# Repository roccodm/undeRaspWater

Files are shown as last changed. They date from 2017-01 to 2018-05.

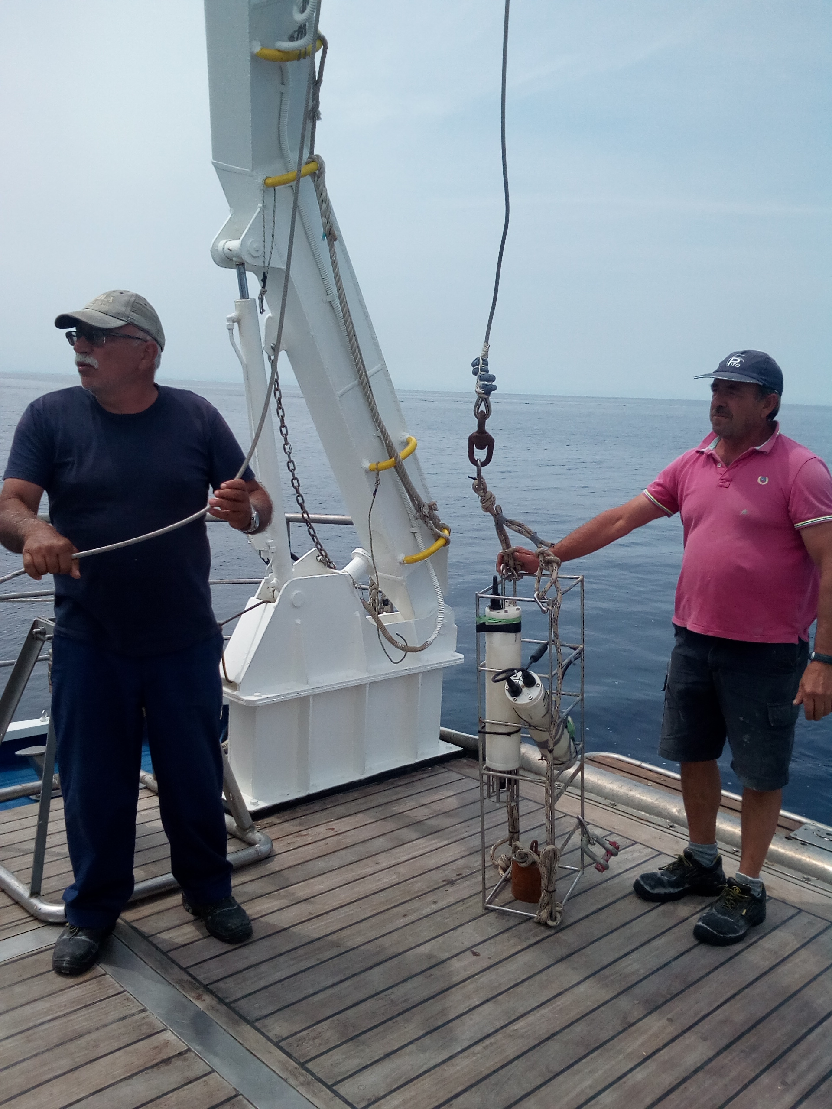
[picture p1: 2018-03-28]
Images/test/IMG_20170610_120925.jpg

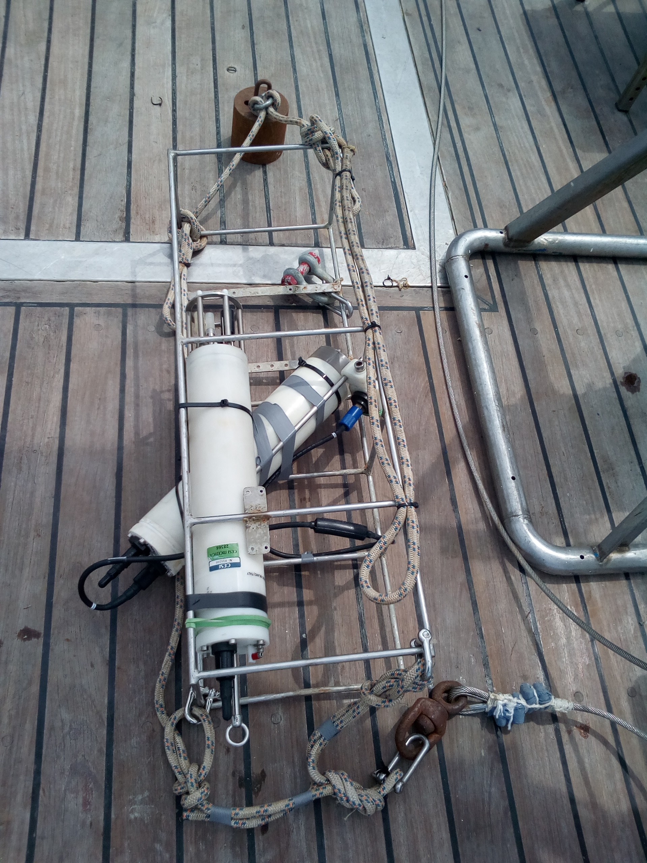
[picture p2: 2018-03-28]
Images/test/IMG_20170610_120815.jpg

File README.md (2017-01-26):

# undeRaspWater

Some useful links:
https://blog.retep.org/2014/02/15/connecting-an-arduino-to-a-raspberry-pi-using-i2c/

https://www.futurashop.it/Allegato_PDF_IT/7100-FT1073K.pdf

https://oscarliang.com/raspberry-pi-arduino-connected-i2c/

http://int03.co.uk/blog/2015/01/11/raspberry-pi-gpio-states-at-boot-time/
https://www.raspberrypi.org/documentation/configuration/pin-configuration.md

Per il voltmetro/amperometro:
http://www.adrirobot.it/arduino/voltmetro_amperometro/Arduino_voltmetro-amperometro.htm

Sulla raspberry vanno dissaldate le resistenza R1 e R2 per garantire il funzionamento del bus I2C quando è spenta. Il pullup è sulla scheda RTC, magari prevedere un pullup da 10K di backup

Per il driver dei led: http://electronics-diy.com/electronic_schematic.php?id=1012

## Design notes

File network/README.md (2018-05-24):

= Networking scripts =

A small script to provied information on networking performance

== Usage ==

You need `iperf3`, `ping`, `sed`, `tr` installed on your machine and the raspberry PI.

- On the RPI, run: `iperf3 -s -J` (`-J` ensures json output)
- On your computer, run: `sh network_test.sh RPI_IP` (where `RPI_IP` is the network address of the raspberry PI)
- Wait for script completion, you will get an output like: `Written log file to: network_test-TIMESTAMP.log`.
  That file will contians JSON data on the network tests.

You can invert the commands between the RPI and your computer if you feel the RPI might suffer when running as server.
It would be, in any case, good to make a comparison between the two logs.

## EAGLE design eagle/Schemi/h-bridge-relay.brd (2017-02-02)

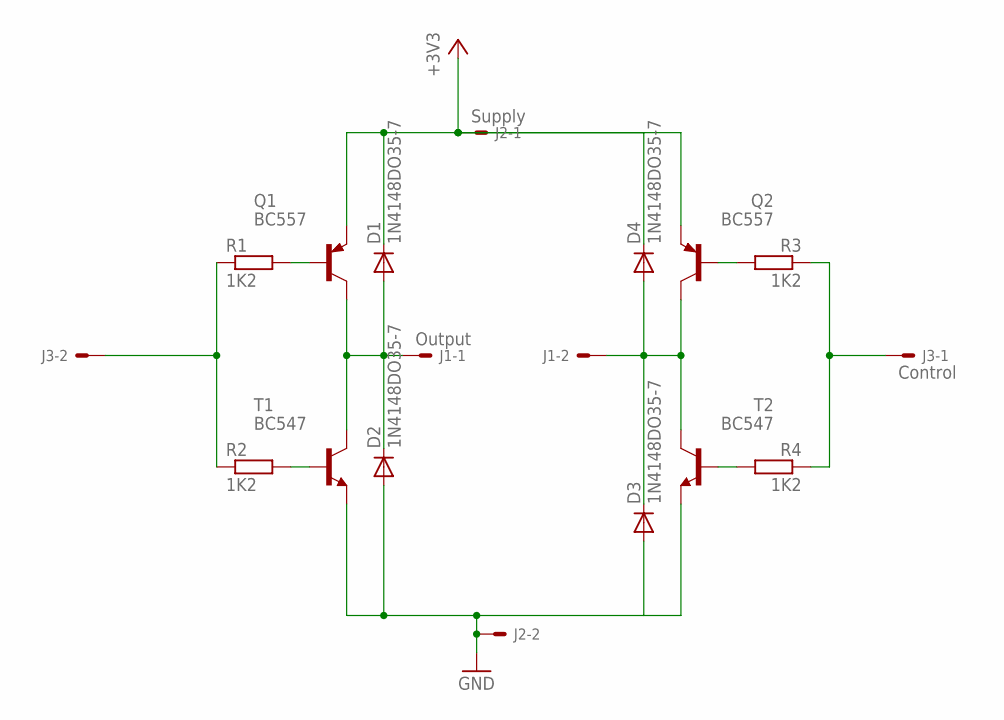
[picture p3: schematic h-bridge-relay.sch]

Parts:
D1, D2, D3, D4: 1N4148DO35-7; DO35-7
J1: Output; 6410-02
J2: Supply; 6410-02
J3: Control; 6410-02
Q1, Q2: BC557; TO92
R1, R4: 1K2; 0207/7
R2: 1K2; 0207/12
R3: 1K2; 0207/2V
T1, T2: BC547; TO92

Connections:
+3V3: D1.C, D4.C, J2.1, Q1.1 (E), Q2.1 (E)
GND: D2.A, D3.A, J2.2, T1.1 (E), T2.1 (E)
unnamed: R2.2, T1.2 (B)
unnamed: Q1.2 (B), R1.2
unnamed: Q2.2 (B), R3.2
unnamed: R4.2, T2.2 (B)
unnamed: D1.A, D2.C, J1.1, Q1.3 (C), T1.3 (C)
unnamed: D3.C, D4.A, J1.2, Q2.3 (C), T2.3 (C)
unnamed: J3.1, R3.1, R4.1
unnamed: J3.2, R1.1, R2.1

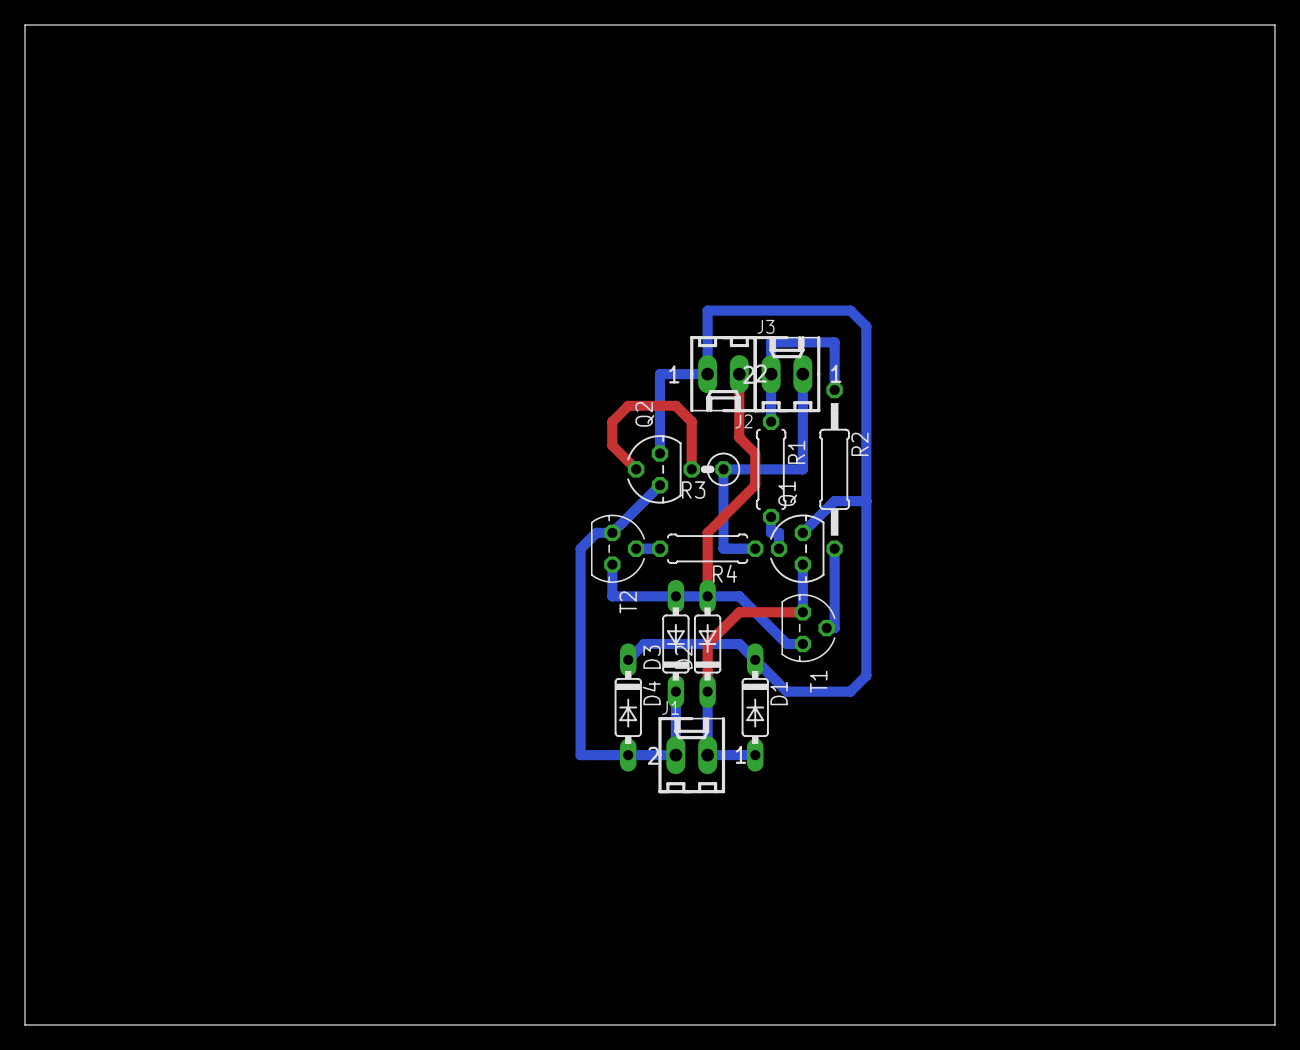
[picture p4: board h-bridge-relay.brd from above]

Board: 2 copper layers, 100.0 x 80.0 mm, 15 parts (0 on the bottom side), 10 nets.

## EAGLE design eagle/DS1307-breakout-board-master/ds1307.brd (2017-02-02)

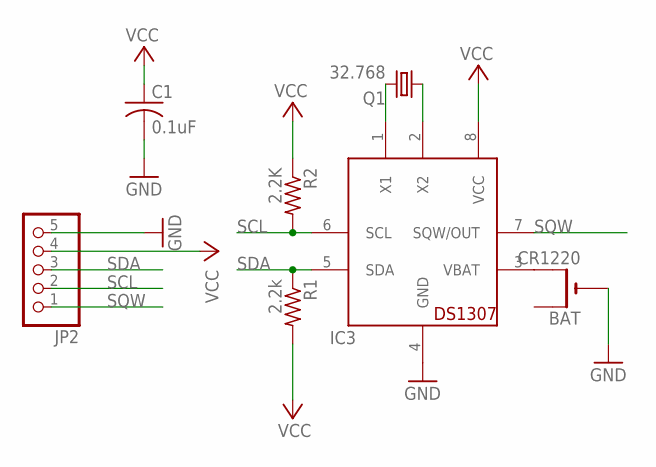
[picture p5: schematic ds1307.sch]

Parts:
BAT: CR1220; CR1220-THM
C1: 0.1uF; C025-025X050
IC3: DS1307; DIL08
JP2: PINHD-1X5; 1X05
Q1: 32.768; TC38H
R1: 2.2k; 0207/10
R2: 2.2K; 0207/10

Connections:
GND: BAT.-, C1.2, IC3.4 (GND), JP2.5
unnamed: IC3.1 (X1), Q1.2
unnamed: IC3.2 (X2), Q1.1
unnamed: BAT.+2 (+1), IC3.3 (VBAT)
SCL: IC3.6 (SCL), JP2.2, R2.2
SDA: IC3.5 (SDA), JP2.3, R1.1
SQW: IC3.7 (SQW/OUT), JP2.1
VCC: C1.1, IC3.8 (VCC), JP2.4, R1.2, R2.1

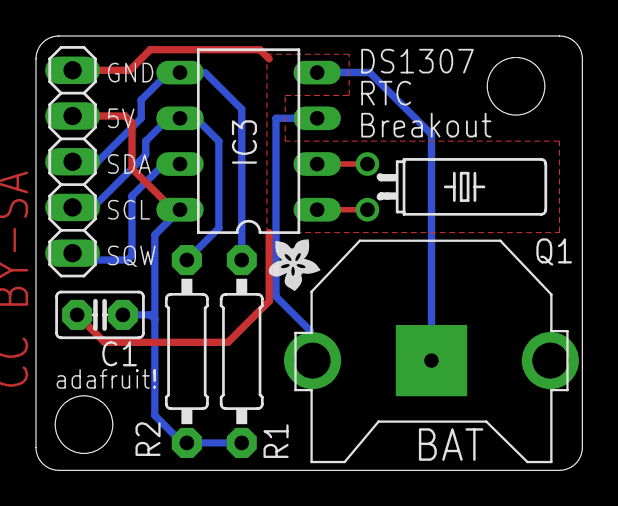
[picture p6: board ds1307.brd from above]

Board: 2 copper layers, 30.4 x 24.1 mm, 8 parts (0 on the bottom side), 8 nets.

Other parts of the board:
U$1: ADAFRUIT200MIL

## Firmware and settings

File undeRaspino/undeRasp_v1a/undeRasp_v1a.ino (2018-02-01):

/*************************************************************************************** 
 *  UnderRaspino
 ***************************************************************************************
 *  v. 1.0a
 *  by Rocco De Marco - rocco.demarco@an.ismar.cnr.it
 ***************************************************************************************/

// MESSAGES
#define START_MSG "\n\nUnderRaspino Ready."
#define I2C_INIT_FAIL "FATAL: i2c bus error"
#define RTC_INIT_FAIL "FATAL: RTC error"
#define LOWBAT "Low battery to start RB"
#define RASP_FAIL "Unable to powerup RB"
#define RASP_NO_HB "Unable to receive Heartbeat from RB"
#define RASP_STARTING "Starting RB"
#define RASP_STOP "RB stopped"
#define MENU1 "\nA\tpower used(A)\nC\tARD temperature\nd/D\tread/write EEPROM datestam (YYMMDDHHMMXXX)\nE/e\tclear/read last error in eprom"
#define MENU2 "\nH/h\tset/read heartbeat\nK/k\tenable/disable RB serial out\nL/l\tTurn on/off mosfet\nM\tSecs left to start RB\nO/o\tset/read keep on RB (use q to quit)\nP/p\tenable/disable ARD serial out\nQ\tQuit RB"
#define MENU3 "\nR\tRB running status\nS/s\tstart/stop RB relay\nT/t\tSet/read RTC (YYMMDDHHMMSS)\nV\tread voltage\nW\tread watt\n?\tPrint this menu"

// ERR CODES
#define I2C_ERRCODE 81
#define RTC_ERRCODE 82
#define LOWBAT_ERRCODE 83
#define RASP_FAIL_ERRCODE 84
#define RASP_NO_HB_ERRCODE 85

// CONFIG
#define VCC 3.3
#define SERIAL_RASPBERRY_PIN 13
#define SERIAL_ARDUINO_PIN 12
#define RELAY_SET_PIN 9
#define RELAY_RESET_PIN 8
#define OK_LED_PIN 7
#define FAIL_LED_PIN 6
#define RASPBERRY_STATUS_PIN 5
#define MOSFET_PIN 4
#define BAUD_RATE 9600
#define VOLTAGE_PIN A0
#define AMPERE_PIN A1
#define I2C_ADDRESS 0x04
#define I2C_SDA A4
#define I2C_SCL A5
#define RTC_MIN_DATE 1483228800   //1/1/2017 0:0:0
#define BUFFSIZE 21
#define R_ALPHA 0.152             // for V read purpose, R partitor coeff.
#define RASP_SHUTDOWN_TIME 30     // delay for shutdown in seconds
#define MAX_TRY 5                 // max raspberry starting tentatives
#define TRY_DELAY 30              // delay (between tests) in seconds
#define MIN_BATTERY_VOLTAGE 9     // minimum voltage to start raspberry in safe
#define MIN_RASPBERRY_DELAY 10    // in minutes
#define ALT_SAMPLING_TIME 120     // alternative sampling time in case of heartbeat fail. In seconds

// INCLUDES
#include <Wire.h>
#include "RTClib.h"
#include <EEPROM.h>
//#include <avr/wdt.h>      // Watchdog actually not working on arduino pro mini :( Stuks in a reset loop 

// GLOBAL VARS
RTC_DS1307 RTC;
DateTime now;
char buffer[BUFFSIZE];    // general purpose global buffer
bool error_status=false;  // flag setted up in case of fatal errors
bool rasp_running=false;  // raspberry running status flag
bool halt_request=false;  // raspberry asks for halt
bool keep_on=false;
bool heartbeat=false;     // Setted from raspberry via i2c
double i2c_val;           // return value for i2c operations
uint32_t wt=0;            // waketime unix stamp
int unresponsive_count=0; // time incremental counter used in failure cases

/*
 * Function error_handler(errcode, msg)
 * 1) prints an error message on serial connection
 * 2) sets a errcode in eeprom 
 * 3) sets to true global variable error_status
 * 4) turns on a red led
 */
void error_handler(char errcode, const char * msg){
   Serial.println(msg);
   error_status=true; 
   EEPROM.write(7,errcode);
   digitalWrite(OK_LED_PIN,0);
   digitalWrite(FAIL_LED_PIN,1);  // Turn on red led
}

/*
 * Function get_pin_median(pinNumber, readDelay)
 * 
 * Sometimes the adc could read dirty values. To avoid wrong values in critical operations
 * more values are read and stored in an ordered array of odd number of elements. 
 * Sorting the array, the bad value will go in a boundary and, returning the median value
 * (the central element in the array), it's highly probable to get a good value.
 * 
 * The InsertionSort algorithm has been used to sort the values, that is pretty fast (such 
 * as the quicksort algorithm!!!) for small array (under 10 element, optimus is 7).
 * 
 * Input:
 *   PinNumber: analog pin to be read
 *   Delay: optional delay between read
 * Output:
 *   The median value of the array of seven reads (integer)
 */

int get_pin_median (int pinNumber, int readDelay=0){
   int value,v[7];         
   for(int n=0;n<7;n++){                            
      int i=0;
      value=analogRead(pinNumber);
      while (i<n and value<=v[i]) i++;
      for (int j=n-1;j>=i;j--) v[j+1]=v[j];
      v[i]=value;
      delay(readDelay);
  }
  return v[3];
}


/*
 * function rasp_relay (set)
 * turn on/off raspberry
 * sets the global var "rasp_running"
 */

double rasp_relay(bool set){
   if (set) {
       digitalWrite(RELAY_SET_PIN,1);
       delay(100);
       digitalWrite(RELAY_SET_PIN,0);
       rasp_running=true;
       return 1;
   } else {
       digitalWrite(RELAY_RESET_PIN,1);
       delay(100);
       digitalWrite(RELAY_RESET_PIN,0);       
       rasp_running=false;
       return 0;
   }
   
}
/*
 * EPROM data structure
 * ----------------------------------------
 * byte | value
 * ----------------------------------------
 *   1  | Year, last two digits  
 *   2  | Month
 *   3  | Day
 *   4  | Hour
 *   5  | Minute
 *   6  | Timestep for delay (minutes)
 *   7  | Last error code
 * ----------------------------------------
 */

/*
 * Function read_eprom_date()
 * read the eeprom date,time and timestem and returns it in global var buffer
 */
double read_eprom_datetime(){ 
   sprintf(buffer,"%02d%02d%02d%02d%02d%03d",EEPROM.read(1),EEPROM.read(2),EEPROM.read(3),
           EEPROM.read(4),EEPROM.read(5),EEPROM.read(6));  
   // returns -2 that means the the return values are stored on global buffer[]
   return -2;
}


/*
 * Function set_eprom_datetime(string)
 * sets the startup datetime  to given value
 * string format: YYMMDDHHMMXXX where XXX is timestep (max 250)
 */


double set_eprom_datetime(char *data){
   int year=*data * 10 + *(data+1);
   int month=*(data+2) * 10 + *(data+3);
   int day=*(data+4) * 10 + *(data+5);
   int hour=*(data+6) * 10 + *(data+7);
   int minute=*(data+8) * 10 + *(data+9);
   int timestep=*(data+10) * 100 + *(data+11) * 10 + *(data+12);
   if (year<17 || month<=0 || month>12 || day<=0 || day >31 || hour>=24 || minute>=60 || 
       timestep <=0 || timestep >250) return -1.4;  // Problem in conversion
   EEPROM.write(1,year);
   EEPROM.write(2,month);
   EEPROM.write(3,day);   
   EEPROM.write(4,hour);
   EEPROM.write(5,minute);
   EEPROM.write(6,timestep);  
   update_waketime(); 
   sprintf(buffer,"ok");
   return -2;
}

/*
 * Function set_rct_datetime(string)
 * sets the rtc datetime to given value
 * string format: YYMMDDHHMMSS
 */

double set_rtc_datetime(char *data){
   int year=*data * 10 + *(data+1);
   int month=*(data+2) * 10 + *(data+3);
   int day=*(data+4) * 10 + *(data+5);
   int hour=*(data+6) * 10 + *(data+7);
   int minute=*(data+8) * 10 + *(data+9);
   int second=*(data+10) * 10 + *(data+11);
   RTC.adjust(DateTime(year+2000,month,day,hour,minute,second));
   return 1;
}

/*
 * Function update_waketime()
 * 
 * Read the eprom and the next raspberry wake time
 * stores the result, in unix time format in the global wt
 */
void update_waketime(){
   DateTime ora(EEPROM.read(1)+2000,
                EEPROM.read(2),
                EEPROM.read(3),
                EEPROM.read(4),
                EEPROM.read(5),
                00);
   wt=ora.unixtime(); 
}

/*
 * Function next_waketime()
 * 
 * Increase the global wt (waketime) variable of minutes stored in flash
 */
void next_waketime(){
   now=RTC.now();
   wt=now.unixtime();
   wt+=EEPROM.read(6)*60;
}

/*
 * Function start_raspberry
 * start raspberry and check for heartbeat
 * MAX_TRY are performed, waiting for TRY_DELAY to check for heartbeat
 */

int start_raspberry(){
   if (user_interface("V")>MIN_BATTERY_VOLTAGE){     // if enought battery...
      Serial.println(RASP_STARTING);
      next_waketime();    // calculate next waketime
      rasp_relay(true);   // turn on raspberry
      // check raspberry feedback
      if (!digitalRead(RASPBERRY_STATUS_PIN)) {
          rasp_relay(true); // try again activating relay
          delay(2000);      // wait for a couple of seconds
          if (!digitalRead(RASPBERRY_STATUS_PIN)) { // test again
             error_handler(RASP_FAIL_ERRCODE,RASP_FAIL);
             return -1;
          }
      }
      //waiting from raspberry heartbeat
      for (int i=0; i<MAX_TRY; i++){
         for (int j=0;j<TRY_DELAY;j++){
            delay(1000);
            //wdt_reset();
            if (heartbeat) {
               Serial.println("Ricevo heartbeat");
               i=MAX_TRY;   // exiting from delay loop
               break;
               
            }
         }
      }      
      if (!heartbeat){
         error_handler(RASP_NO_HB_ERRCODE,RASP_NO_HB);
      } 
      heartbeat=false;     // Reset heartbeat
   } else {
      error_handler(LOWBAT_ERRCODE,LOWBAT);
   } //end cycle battery low
}

/* 
 * function quit_raspberry()
 * simple helper to wait for a delay and turn off raspberry
 */
double quit_raspberry(){
   halt_request=true;
   keep_on=false;
   Serial.println(RASP_STOP);
   return 1;
}


/*
 * function warning_led()
 * turns on the status led in yellow color for some second
 * a two pin red/green led in connected on OK_LED_PIN and FAIL_LED_PIN
 */
void warning_led() {
   int i=0;
   while (i++<1000){
      digitalWrite(OK_LED_PIN,0);
      digitalWrite(FAIL_LED_PIN,1);
      delay(2);
      digitalWrite(FAIL_LED_PIN,0);
      digitalWrite(OK_LED_PIN,1);
      delay(2);                         
   }
   digitalWrite(OK_LED_PIN,0);      
}

/*
 * function warning_led()
 * blink status led in green color for some second
 */
void blink_led() {
   digitalWrite(FAIL_LED_PIN,0);   // just to be sure...
   for (int i=0;i<5;i++){
      digitalWrite(OK_LED_PIN,1);  // turn on green led blinking
      delay(200);
      digitalWrite(OK_LED_PIN,0);
      delay(200);
   }
}


/*
 * Function GetTemp: return internal temperature
 * Credits: http://playground.arduino.cc/Main/InternalTemperatureSensor
 * by: Arduino LLC 
 * Creative Commons Attribution ShareAlike 3.0 
 */
double GetTemp(void)
{
   unsigned int wADC;
   double t;
   ADMUX = (_BV(REFS1) | _BV(REFS0) | _BV(MUX3));
   ADCSRA |= _BV(ADEN); // enable the ADC
   delay(50); // wait for voltages to become stable.
   ADCSRA |= _BV(ADSC); // Start the ADC
   while (bit_is_set(ADCSRA,ADSC));
   wADC = ADCW;
   t = (wADC - 324.31 ) / 1.22;
   return abs(t);
}


/*
 * Function user_interface (cmd_string)
 * It's a middleware between user-interaction (serial or i2c) and i/o functions
 * The first char in cmd_string contains the command selector, the other (optional)
 * chars are used as parameters.
 * Maximum lenght is BUFF_SIZE
 * 
 * Possible return values:
 *  1 = Function executed without problem
 * -1 = Function closed with error
 * -2 = Results stored in global buffer[]
 * any positive number = results from adc or similar
 */

double user_interface (char *cmd_string){
   char str[20];
   int i;
   char cmd=cmd_string[0];   
   double retval=-1;
   switch (cmd){
      case 'A':  // Ampere read /////////////////////////////////////////////////////////////////////////////////////////////
          retval=((get_pin_median(AMPERE_PIN)*VCC/1024)-2.5)/0.185;
          break;
      case 'C':  // internalTemperature read ////////////////////////////////////////////////////////////////////////////////
          retval=GetTemp();
          break;
      case 'd':  // read Eprom Date /////////////////////////////////////////////////////////////////////////////////////////
          retval=read_eprom_datetime();
          break;
      case 'D':  // set Eprom Date //////////////////////////////////////////////////////////////////////////////////////////
          if (strlen(cmd_string)!=14) return -1.1;                        // fixed size: 14 char
          for (i=0;i<13;i++){ 
              if (cmd_string[i+1]<48 or cmd_string[i+1]>57) str[i]=0;  // only number accepted
              else str[i]=cmd_string[i+1]-48;                          // pretty simple atoi
          }
          retval=set_eprom_datetime(str);
          break;
      case 'E':  // clear last error in EPROM ///////////////////////////////////////////////////////////////////////////////
          EEPROM.write(7,0);
          retval=1;
          break;
      case 'e':  // read last error in EPROM ////////////////////////////////////////////////////////////////////////////////
          retval=EEPROM.read(7);
          break;
      case 'H':  // set earthbit ////////////////////////////////////////////////////////////////////////////////////////////
          heartbeat=true;
          retval=1;    
          break;
      case 'h':  // read heartbeat //////////////////////////////////////////////////////////////////////////////////////////
          retval=heartbeat;    
          break;     
      case 'K':  // enable raspberry serial output (and disable arduino output) /////////////////////////////////////////////
          digitalWrite(SERIAL_ARDUINO_PIN,0);       
          digitalWrite(SERIAL_RASPBERRY_PIN,1);
          retval=1;
          break;     
      case 'k':  // disable raspberry serial output /////////////////////////////////////////////////////////////////////////
          digitalWrite(SERIAL_RASPBERRY_PIN,0);       
          retval=1;
          break;     
      case 'l':  // Turn off mosfet /////////////////////////////////////////////////////////////////////////////////////////
          digitalWrite(MOSFET_PIN,0);       
          retval=0;
          break;
      case 'L':  // Turn on mosfet //////////////////////////////////////////////////////////////////////////////////////////
          digitalWrite(MOSFET_PIN,1);       
          retval=1;
          break;          
      case 'M':  // Missing seconds to start raspberry //////////////////////////////////////////////////////////////////////
          if (!rasp_running) {
             now=RTC.now(); 
             retval=wt-now.unixtime();
          }
          break;
      case 'O':  // keep on raspberry ///////////////////////////////////////////////////////////////////////////////////////
          keep_on=true;
          retval=1;    
          break;
      case 'o':  // read heartbeat //////////////////////////////////////////////////////////////////////////////////////////
          retval=keep_on;    
          break; 
      case 'P':  // enable arduino serial output (and disable raspberry output) /////////////////////////////////////////////
          digitalWrite(SERIAL_ARDUINO_PIN,1);       
          digitalWrite(SERIAL_RASPBERRY_PIN,0);
          Serial.println(START_MSG);
          user_interface("?");
          retval=1;
          break;     
      case 'p':  // disable arduino serial output //////////////////////////////////////////////////////////////////////////
          digitalWrite(SERIAL_ARDUINO_PIN,0);
          retval=1;
          break; 
      case 'Q':  // quit raspberry with delay ///////////////////////////////////////////////////////////////////////////////
          retval=quit_raspberry();
          break;
      case 'R':  // return raspberry running status /////////////////////////////////////////////////////////////////////////
          retval=rasp_running;
          break;
      case 'S':   // Start raspberry ////////////////////////////////////////////////////////////////////////////////////////        
          retval=rasp_relay(true);
          break;
      case 's':   // Stop raspberry immediately//////////////////////////////////////////////////////////////////////////////
          keep_on=false;
          retval=rasp_relay(false);
          break;
      case 'T':  // set rtc datetime ////////////////////////////////////////////////////////////////////////////////////////
          if (!rasp_running) {
             if (strlen(cmd_string)!=13) return -1.1;                        // fixed size: 13 char
             for (i=0;i<12;i++){ 
                 if (cmd_string[i+1]<48 or cmd_string[i+1]>57) str[i]=0;  // only number accepted
                 else str[i]=cmd_string[i+1]-48;                          // pretty simple atoi
             }
             retval=set_rtc_datetime(str);       
          }
          break;         
      case 't':  // return time /////////////////////////////////////////////////////////////////////////////////////////////
          if (!rasp_running) {
             now=RTC.now();
             sprintf(buffer,"%02d/%02d/%04d %02d.%02d.%02d",now.day(),now.month(),
                            now.year(),now.hour(),now.minute(),now.second());
             retval=-2;  // means print buffer
          }
          break;    
      case 'V':  // Voltage read ////////////////////////////////////////////////////////////////////////////////////////////
          retval=(get_pin_median(VOLTAGE_PIN)*VCC/1024)/R_ALPHA;
          break;
      case 'W':  // Watts in use ////////////////////////////////////////////////////////////////////////////////////////////
          retval=user_interface("V")*user_interface("A");
          break;
      case '?':  // print menu //////////////////////////////////////////////////////////////////////////////////////////////
          Serial.print(MENU1);
          Serial.print(MENU2);
          Serial.println(MENU3);          
          retval=1;
          break;          
          
   }
   return retval;
}


/*
 * Function serialEvent()
 * Is called in case of serialEvent
 * 1) assembles the command string
 * 2) calls the user_interface function
 * input is trunked at BUFF_SIZE max lenght
 */

void serialEvent(){
   char data=0;
   int i=0;
   double retval;
   while(Serial.available()) {
      data=Serial.read();    
      if (i<BUFFSIZE-1) buffer[i++]=data;
   }
   buffer[i]='\0';
   Serial.print("CMD ");
   Serial.print(buffer);
   Serial.print(":");
   retval=user_interface(buffer);
   if (retval==-2) Serial.println(buffer);
   else Serial.println(retval);
}


void i2c_receive(int count){
   char data=0;
   int i=0;
   while(Wire.available()) {    
      data=Wire.read();          
      if (i<BUFFSIZE-1) buffer[i++]=data;
   }
   buffer[i]='\0';
   i2c_val=user_interface(buffer);
   if (i2c_val!=-2) dtostrf(i2c_val,6,3, buffer);
}

void i2c_send(){
   Wire.write(buffer);  
}
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
void loop() {
  if(!error_status){                // if no error...
     if(!rasp_running){             // when raspberry is off
        now=RTC.now();              // check the time
        if(wt<now.unixtime()){      // if it's time to start...
           start_raspberry();       // ... start
        } 
     } else {                       // if raspberry is running...
        if (!heartbeat){            // if raspberry doesn't set heartbeat.... 
           // Without heartbeat, wait for fixed time
           for (int i=0;i<=ALT_SAMPLING_TIME;i++){
              delay(1000);
              //wdt_reset();
              if (heartbeat) break;
           }
           if (!heartbeat) { // if not heartbeat received after delay
              // Calculate next restart... 
              now=RTC.now();
              if (wt<now.unixtime()) wt=now.unixtime()+MIN_RASPBERRY_DELAY*60;   
              rasp_relay(false);        // ... and stop raspberry 
              EEPROM.write(7,RASP_NO_HB_ERRCODE); // issue error on EEPROM             
           }                     
        }
        heartbeat=false;            // reset heartbeat
        if (halt_request) {         // if it's time to stop
           // for long delay is needed to split in part to avoid watchdog reset
           for (int i=0;i<=RASP_SHUTDOWN_TIME;i++){
              delay(1000);
              //wdt_reset();
           }
           // before stop, avoiding fast restart adding MIN_RASPBERRY_DELAY
           now=RTC.now();
           if (wt<now.unixtime()) wt=now.unixtime()+MIN_RASPBERRY_DELAY*60;   
           rasp_relay(false);        // stop raspberry
           halt_request=false;       // clear request 
        }
     } //end cycle rasberry running
  } else { 
     // if I2C or RTC are not working, try to work with raspberry in unresponsive way
     if (EEPROM.read(7)==I2C_ERRCODE or EEPROM.read(7)==RTC_ERRCODE)
     { 
         if (!rasp_running){  // wait cycle
            if (unresponsive_count++>wt) {  // if is time...
              digitalWrite(FAIL_LED_PIN,0); // ... turn off red light
              wt=ALT_SAMPLING_TIME+RASP_SHUTDOWN_TIME*2;; // calculate running time
              rasp_relay(true);             // turn on raspberry
              unresponsive_count=0;         // reset counter
            }
         } else { // work delay cycle
            if (unresponsive_count++>wt) {  // if is time...
              digitalWrite(FAIL_LED_PIN,0); // ... turn off red light
              wt=EEPROM.read(6)*60;  // recalculate wait time
              if (wt<MIN_RASPBERRY_DELAY*60) wt=MIN_RASPBERRY_DELAY*60;
              rasp_relay(false);            // turn off raspberry
              unresponsive_count=0;         // reset counter
            }
         }
     }
  }
  delay(1000);  // DO NOT CHANGE
 

}

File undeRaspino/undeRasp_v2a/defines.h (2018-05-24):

#ifndef DEFINES_H
#define DEFINES_H

#include "Arduino.h"
#include "RTClib.h"
#include <EEPROM.h>
#include <Wire.h>

typedef uint32_t time_t;

#define DEBUG 1

#if DEBUG
#define BB_DEBUG 1

#if BB_DEBUG
#define DBG_PIN 2
#endif

#endif

#define DIRECT_ADC 0

// Function to use program memory for strings
#define PS(str) (strcpy_P(prog_buf, PSTR(str)), prog_buf)
extern char prog_buf[100]; // initialized in utils.h

// LED States
#define LED_OFF 0
#define LED_CHECKING 1
#define LED_OK 2
#define LED_WARNING 3
#define LED_ERROR 4

// EEPROM locations
#define EEPROM_YEAR 1
#define EEPROM_MONTH 2
#define EEPROM_DAY 3
#define EEPROM_HOUR 4
#define EEPROM_MINUTE 5
#define EEPROM_STEP 6
#define EEPROM_ERROR 7
#define EEPROM_MODE 8
#define EEPROM_APP_ERROR 9

// Messages
#define MSG_START PS("\n\nUnderRaspino Ready.")
#define MSG_I2C_FAIL PS("FATAL: i2c bus error")
#define MSG_I2C_BUSY PS("FATAL: i2c bus is busy (rpi is running)")
#define MSG_RTC_FAIL PS("FATAL: RTC error")
#define MSG_RTC_INVALID_DATE PS("FATAL: RTC initial date is invalid")
#define MSG_VOLTAGE_LOW PS("Battery too low to start RPI")
#define MSG_VOLTAGE_CRITICAL PS("Battery level critical. Entering safe mode")

#define MSG_TOO_SHORT PS("too short")
#define MSG_INVALID_INT PS("invalid int")
#define MSG_OK PS("ok")

#define MSG_RPI_START PS("Starting Raspberry")
#define MSG_RPI_STOP PS("Stopping Raspberry")

#define MSG_RPI_NO_POWER PS("RPI is unpowered")
#define MSG_RPI_NO_RESPONSE PS("RPI is unresponsive")
#define MSG_RPI_NO_BOOT PS("RPI failed to boot")

// ERR CODES
#define ERR_I2C_FAIL 11
#define ERR_I2C_BUSY 12

#define ERR_RTC_FAIL 21
#define ERR_RTC_INVALID_DATE 22

#define ERR_VOLTAGE_LOW 31
#define ERR_VOLTAGE_CRITICAL 32

#define RPI_ERR_UNPOWERED 41    // RPI was powered on, but looks unpowered
#define RPI_ERR_BOOT_FAILED 42  // RPI has power, but looks unable to boot
#define RPI_ERR_UNRESPONSIVE 43 // RPI booted, but seems unresponsive now

// CONFIG
#define VCC 3.3
#define MOSFET_PIN 4
#define RASPBERRY_STATUS_PIN 5
#define FAIL_LED_PIN 6
#define OK_LED_PIN 7
#define RELAY_RESET_PIN 8
#define RELAY_SET_PIN 9
#define SERIAL_ARDUINO_PIN 12
#define SERIAL_RASPBERRY_PIN 13
#define BAUD_RATE 9600
#define VOLTAGE_PIN A0
#define AMPERE_PIN A1
#define I2C_ADDRESS 0x04
#define I2C_SDA A4
#define I2C_SCL A5
#define RTC_MIN_DATE 1483228800 // 1/1/2017 0:0:0
#define BUFFSIZE 21
#define R_ALPHA 0.152      // for V read purpose, R partitor coeff.
#define VOLTAGE_LOW 9.5    // minimum operation voltage
#define VOLTAGE_CRITICAL 9 // critical voltage

#endif

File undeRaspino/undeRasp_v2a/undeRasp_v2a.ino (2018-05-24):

// INCLUDES
#include "defines.h"
#include "rpi.h"
#include "utils.h"

// GLOBAL VARS
char serial_buf[BUFFSIZE]; // serial buffer
short serial_pos = -1;     // serial position (incremented at the beginning)

char i2c_buf[BUFFSIZE];     // i2c buffer
char i2c_out_buf[BUFFSIZE]; // i2c output buffer

char out_buf[BUFFSIZE]; // output buffer

double user_interface(char *cmd_s) {
   int i;
   int dpow;
   char cmd = cmd_s[0];
   double retval = -1;
   switch (cmd) {
   case '?': // print menu
      print_menu();
      retval = 1;
      break;
   case 'a': // get ampere
      retval = get_ampere();
      break;
   case 'c': // get temperature
      retval = get_temperature();
      break;
   case 'D': // set eeprom date
      retval = set_eeprom_datetime(&cmd_s[1], out_buf);
      rpi_update_waketime();
      break;
   case 'd': // read eeprom date and wake delay
      retval = get_eeprom_datetime(out_buf);
      break;
   case 'E': // clear last error
      reset_error();
      retval = 1;
      break;
   case 'e': // read last error
      retval = get_last_error();
      break;
   case 'H': // set heartbeat
      rpi_set_booted();
      retval = 1;
      break;
   case 'L': // turn on mosfet
      set_mosfet(true);
      retval = 1;
      break;
   case 'l': // turn off mosfet
      set_mosfet(false);
      retval = 0;
      break;
   case 'M': // set operation mode
      if (strlen(cmd_s) < 2)
         break;
      retval = rpi_set_run_mode_s(&cmd_s[1], out_buf);
      break;
   case 'm': // get operation mode
      retval = rpi_get_run_mode();
      break;
   case 'O': // set RPI manual mode
      rpi_set_manual(true);
      retval = 1;
      break;
   case 'o': // unset RPI manual mode
      rpi_set_manual(false);
      retval = 0;
      break;
   case 'P': // enable RPI/disable arduino serial output
      rpi_set_serial(true);
      retval = 1;
      break;
   case 'p': // disable RPI/enable arduino serial output
      rpi_set_serial(false);
      retval = 1;
      break;
   case 'Q':
      rpi_set_halting(true);
      retval = 1;
      break;
   case 'q':
      rpi_set_halting(false);
      retval = 0;
      break;
   case 'R':
      if (!rpi_is_manual()) {
         sprintf(out_buf, PS("Not in manual mode"));
         retval = -2;
      } else {
         rpi_setup(); // Reset RPI status
         retval = 1;
      }
      break;
   case 'r': // get RPI running status
      retval = rpi_get_status();
      break;
   case 'S': // start RPI
      rpi_start();
      retval = 1;
      break;
   case 's': // stop RPI
      rpi_stop();
      retval = 0;
      break;
   case 'T': // set RTC datetime
      if (!rpi_has_power()) {
         retval = set_rtc_datetime_s(&cmd_s[1], out_buf);
      } else {
         retval = set_internal_datetime_s(&cmd_s[1], out_buf);
         if (retval != -2) {
            sprintf(out_buf, PS("RPI is running"));
            retval = -2;
         }
      }
      break;
   case 't': // get RTC datime
      if (!rpi_has_power()) {
         retval = get_rtc_datetime_s(out_buf);
      } else {
         retval = get_internal_datetime_s(out_buf);
      }
      break;
   case 'v': // get voltage
      retval = get_voltage();
      break;
   case 'w': // get watts
      retval = get_watts();
      break;
   case 'Y':
      retval = rpi_set_checks_result(&cmd_s[1], out_buf);
      break;
   case 'y':
      retval = rpi_get_checks_result();
      break;
   case 'z': // get seconds left before starting raspberry
      retval = rpi_get_restart_time_left();
      break;
#if BB_DEBUG
   case '>':
      digitalWrite(DBG_PIN, 1);
      retval = 1;
      break;
   case '<':
      digitalWrite(DBG_PIN, 0);
      retval = 0;
      break;
#endif
   default:
      break; // unknown command
   }
   return retval;
}

/*
 * Function serialEvent()
 * Called when new data is available on the serial
 * 1) assembles the command string
 * 2) calls the user_interface function
 * input is truncated at BUFF_SIZE length
 */

void serialEvent() {
   char data = 0;
   double retval;
   while (Serial.available()) {
      data = Serial.read();
      serial_pos += 1;
      if (serial_pos >= BUFFSIZE) {
         // message too long, wrapping!
         serial_pos = 0;
      }
      serial_buf[serial_pos] = data;
      if (serial_buf[serial_pos] == '\n') {
         serial_buf[serial_pos] = '\0';
         break;
      }
   }
   if (serial_buf[serial_pos] != '\0') {
      return; // message is not over yet
   }
   serial_pos = -1;
   while (Serial.available()) {
      Serial.read(); // trash what's left
   }
   Serial.print("CMD ");
   Serial.print(serial_buf);
   Serial.print(":");
   retval = user_interface(serial_buf);
   if (retval == -2)
      Serial.println(out_buf);
   else
      Serial.println(retval);
}

void i2c_receive(int count) {
   char data = 0;
   int i = 0;
   double retval;
   while (Wire.available()) {
      data = Wire.read();
      if (i < BUFFSIZE - 1)
         i2c_buf[i++] = data;
   }
   i2c_buf[i] = '\0';
   retval = user_interface(i2c_buf);
   if (retval == -2)
      strcpy(i2c_out_buf, out_buf);
   else
      dtostrf(retval, 6, 3, i2c_out_buf);
}

void i2c_send() { Wire.write(i2c_out_buf); }

void setup() {
   // Pin setup
   pinMode(SERIAL_ARDUINO_PIN, OUTPUT);
   pinMode(SERIAL_RASPBERRY_PIN, OUTPUT);
   pinMode(RASPBERRY_STATUS_PIN, INPUT);
   pinMode(RELAY_SET_PIN, OUTPUT);
   pinMode(RELAY_RESET_PIN, OUTPUT);
   pinMode(MOSFET_PIN, OUTPUT);
   pinMode(OK_LED_PIN, OUTPUT);
   pinMode(FAIL_LED_PIN, OUTPUT);
   // Reset pins
   digitalWrite(RELAY_SET_PIN, 0);
   digitalWrite(RELAY_RESET_PIN, 0);
   digitalWrite(MOSFET_PIN, 0);
   digitalWrite(SERIAL_ARDUINO_PIN, 1);

   // Ensure RPI shutdown
   digitalWrite(RELAY_RESET_PIN, 1);
   delay(20);
   digitalWrite(RELAY_RESET_PIN, 0);
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

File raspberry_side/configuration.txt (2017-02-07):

RASPBERRY CONFIGURATION
=======================

1) RTC

1.1) Edit /etc/modules
Add following lines:
-------------------------------
i2c-dev
rtc-ds1307
-------------------------------

1.2) Edit /etc/rc.local
Add following lines:
-------------------------------
echo ds1307 0x68 > /sys/class/i2c-adapter/i2c-1/new_device
hwclock --hctosys
-------------------------------
before "exit 0"


2) Arduino interaction

2.1) Compile/Copy ardui2c in /bin/
2.2) Edit /etc/rc.local
Add following lines:
-------------------------------
nohup /bin/pinger &
nohup python /bin/broadcast_sender.py &
-------------------------------
before "exit 0"

2.3) execute as root...
-------------------------------
cat >/bin/pinger <<EOF
#!/bin/sh

while test 1
do
   /bin/ardui2c H
   sleep 3s
done
EOF

chmod 755 /bin/pinger


cat >/etc/rc6.d/K01arduiQuit <<EOF
#!/bin/bash

/bin/ardui2c Q
EOF
chmod 755 /etc/rc6.d/K01arduiQuit
-------------------------------

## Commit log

2017-01-22 prima stesura con materiale preso in giro
2017-01-24 inserito esempio per arduino
2017-02-02 Riorganizzato repository
    [protocollo i2c rasp2arduino.ods]
2017-02-02 Completato script lato raspberry
    [ds1307.brd, ds1307.sch]
2017-02-02 Aggiunti primi schemi
    [comunicazione seriale.sch, h-bridge-relay.brd, h-bridge-relay.sch]
2017-02-02 Migliorato firmware arduino, spostate routine accensione raspberry in apposita funzione, risolti problemi su wt
    [undeRasp_v1a.ino]
2017-02-03 added 74hc466 on board and added code to manage on arduino
2017-02-03 added hardware feedback from raspberry. Solved some issue
    [undeRasp_v1a.ino]
2017-02-03 rewritten voltage read function
2017-02-06 added watchdog support, rewitten set_rtc_datetime()
    [configuration.txt]
2017-02-06 solved little issues, added python source for broadcast messages
    [broadcast_sender.py, undeRasp_v1a.ino]
2017-02-07 bug risolti su arduino
    [configuration.txt]
2017-02-15 eliminato watchdog (commentate righe): arduino pro mini non lo supporta al momento bene
2018-02-08 Add raspberry pi scripts
2018-02-08 Use single timer (timer1) set to 1hz
2018-02-09 Add heartbeat, voltage, amp, watts, temp to user interface
2018-02-10 Refactor print_menu and atod
2018-02-10 Add error message to set rtc
    [undeRasp_v2a.ino]
2018-02-10 Sort pin order in define
2018-02-11 Add diagram for how Arduino controls RPI
2018-02-11 Small fix to arduino diagram
2018-02-11 keepalive->manual_mode, option to reset RPI state.
    Start in manual mode when compiled for breadboard debug.
    [rpi.ino, undeRasp_v2a.ino]
2018-02-11 Fix setting EEPROM/RTC datetime.
    Properly confiigure restart delay in rpi_setup
    [rpi.ino, undeRasp_v2a.ino, utils.ino]
2018-02-11 Add option to ask RPI shutdown politely.
    Also add option to see cooldown timer
2018-02-12 Serial now expects new line as end of message
    Use separate buffers for i2c and serial input/output
2018-02-12 Small fix to help menu
    [utils.ino]
2018-02-13 Add voltage checks
2018-02-14 Add correctly timed start/stop
    Will skip cycle if RPI is still running or errors happened.
    Convert .ino files to .cpp to get better compiler checks
    Reorganize includes and global vars.
    Support both 8 and 16 mhz cpus
    [defines.h, rpi.cpp, undeRasp_v2a.ino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]
2018-02-15 Use timer 2 for led switching.
    Four states, off, okay, error, warning
    [undeRasp_v2a.ino, utils.cpp]
2018-02-15 Set warning LED when rpi checks failed
    Use defines for EEPROM locations and LED
    [defines.h, rpi.cpp, undeRasp_v2a.ino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]
2018-02-22 Add blinking green led when running checks
    Led turns green when checks successful, turn off after RPI shutdown
2018-02-22 Use a timer to take voltage and current samples
    The get_pin_median function no longer uses delay but rely on samples taken at
    fixed interval.
    [undeRasp_v2a.ino, utils.cpp]
2018-02-22 Add 1 sec delay on setup to populate samples.
    Avoid getting wrong Voltage values in the first few loops.
    [undeRasp_v2a.ino]
2018-02-22 On valid checks only set green LED if first start
    Turn off led otherwise
2018-03-06 ui.py (web interface) almost done; Fixed manual mode in underaspdaemon.py
    [underaspdaemon.py]
2018-03-08 Always shut down RPI on boot
    Do not print error messages if not in debug mode
    [undeRasp_v2a.ino, utils.cpp]
2018-03-09 Do not sample volts and current when reading temp
    analogRead in sampling interrupt seems to screw up the temperature readings
2018-03-11 Implement direct ADC usage.
    Avoid using analogRead which adds delay.
    Analog sensors reading is now done round robin between the desired pins
    [defines.h, undeRasp_v2a.ino, utils.cpp]
2018-03-11 Make TIMER2 more precise on 16mhz CPUs
    Does not play well with 64 bits prescaler, so we use a 2000 hz frequency
    and we skip one in the interrupt
    [undeRasp_v2a.ino]

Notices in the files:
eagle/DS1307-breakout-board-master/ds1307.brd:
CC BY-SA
